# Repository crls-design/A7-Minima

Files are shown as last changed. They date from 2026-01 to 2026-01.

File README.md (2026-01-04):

# A7 Minima

A minimalist Artix-7 SoM in a credit-card form factor.

## Features

- XC7A100T-2 in CSG324 package
- 1GB DDR3 (32-bit, 800 Mbps)
- 32MB QSPI Flash
- On-board USB-to-JTAG + UART
- HDMI source connector
- 64 GPIOs compatible with perfboard
- 8 addressable RGB LEDs
- 2 single-color LEDs
- 3 slide switches
- 1 push button

## Documentation

See [`docs`](./docs/).

## Gallery




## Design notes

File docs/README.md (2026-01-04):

# Documentation

[Schematic](schematic.pdf)

## Pinouts & Template

See [`template`](../vivado/template/) folder for the `.ucf` and `.xdc` files, as well as top module instantiation template.

## Example Projects

- [LED Demo](../vivado/led_demo)
- [DDR3 Memory Test](../vivado/mem_test/)
- [Ben Eater's Breadboard Computer](https://github.com/CharlesSurianto/Ben-8-Bit/)

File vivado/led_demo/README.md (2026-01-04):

# LED Demo

This demo includes RGB binary counter and RGB Larson Scanner (fading variant), both of which are implemented purely in hardware.

## Gallery



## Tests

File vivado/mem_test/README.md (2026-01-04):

# Memory Test

This project implements a basic MicroBlaze system with DDR3 MIG interface running at 400MHz to verify the PCB's layout. Vitis memory tests example is used.

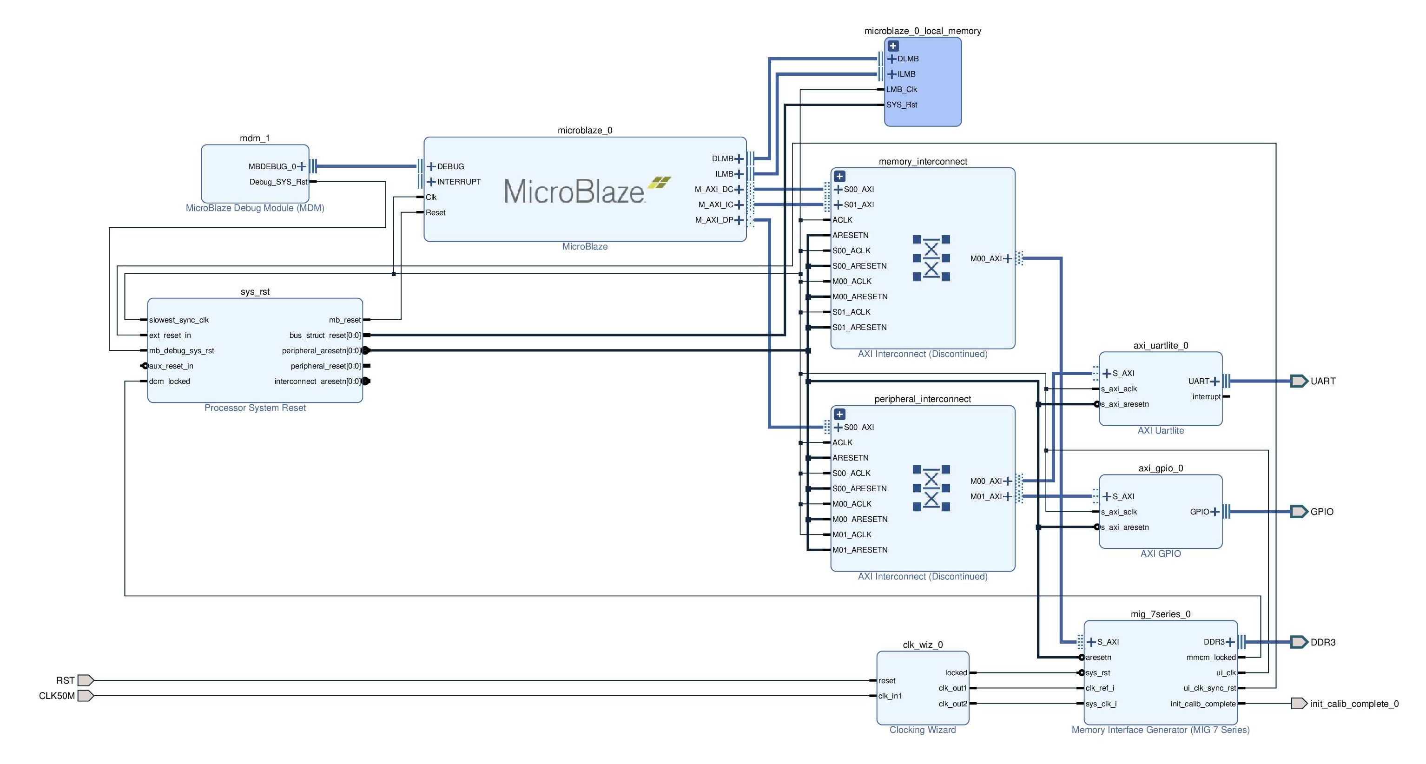
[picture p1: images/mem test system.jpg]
<br>

The MicroBlaze processor is clocked at 100MHz which is generated by the MIG. An external 50MHz oscillator from bank 14 is fed into a clocking wizard to generate 200MHz for `ref_clk` and 400MHz for `sys_clk`.

## Result

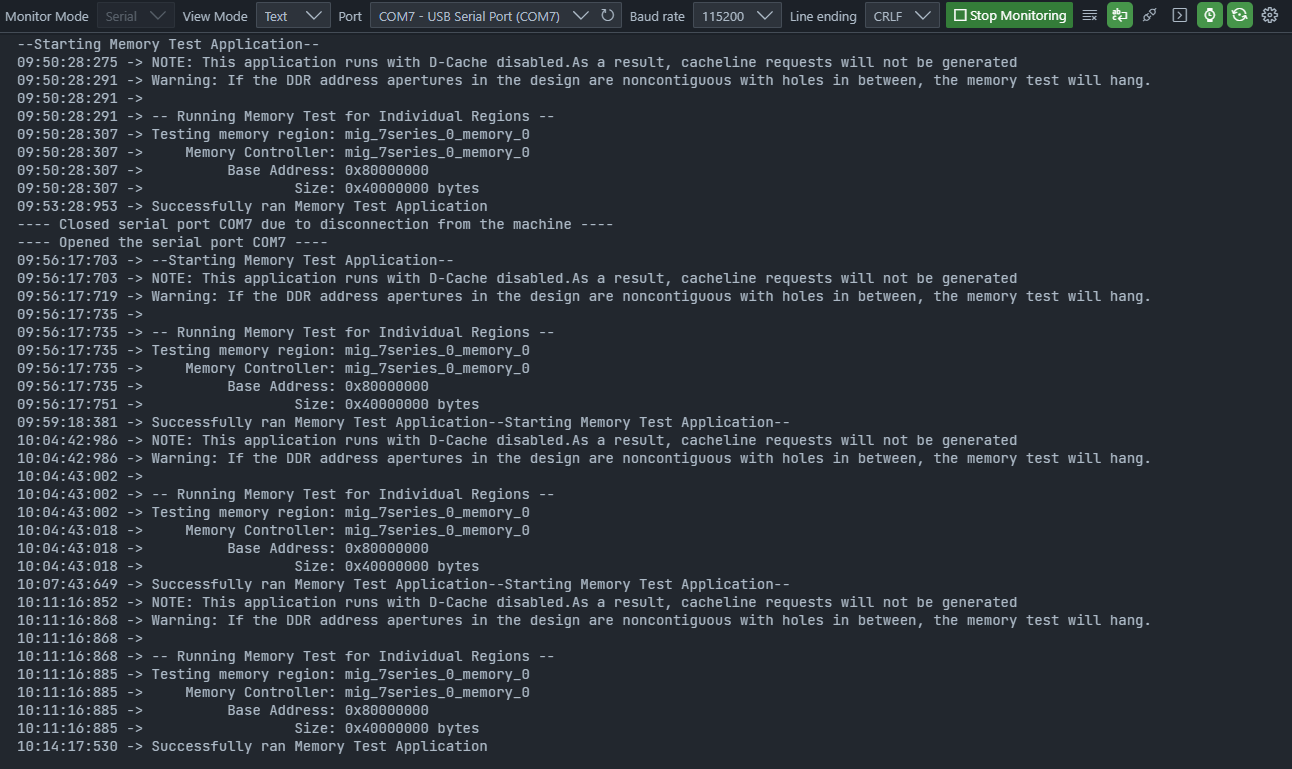
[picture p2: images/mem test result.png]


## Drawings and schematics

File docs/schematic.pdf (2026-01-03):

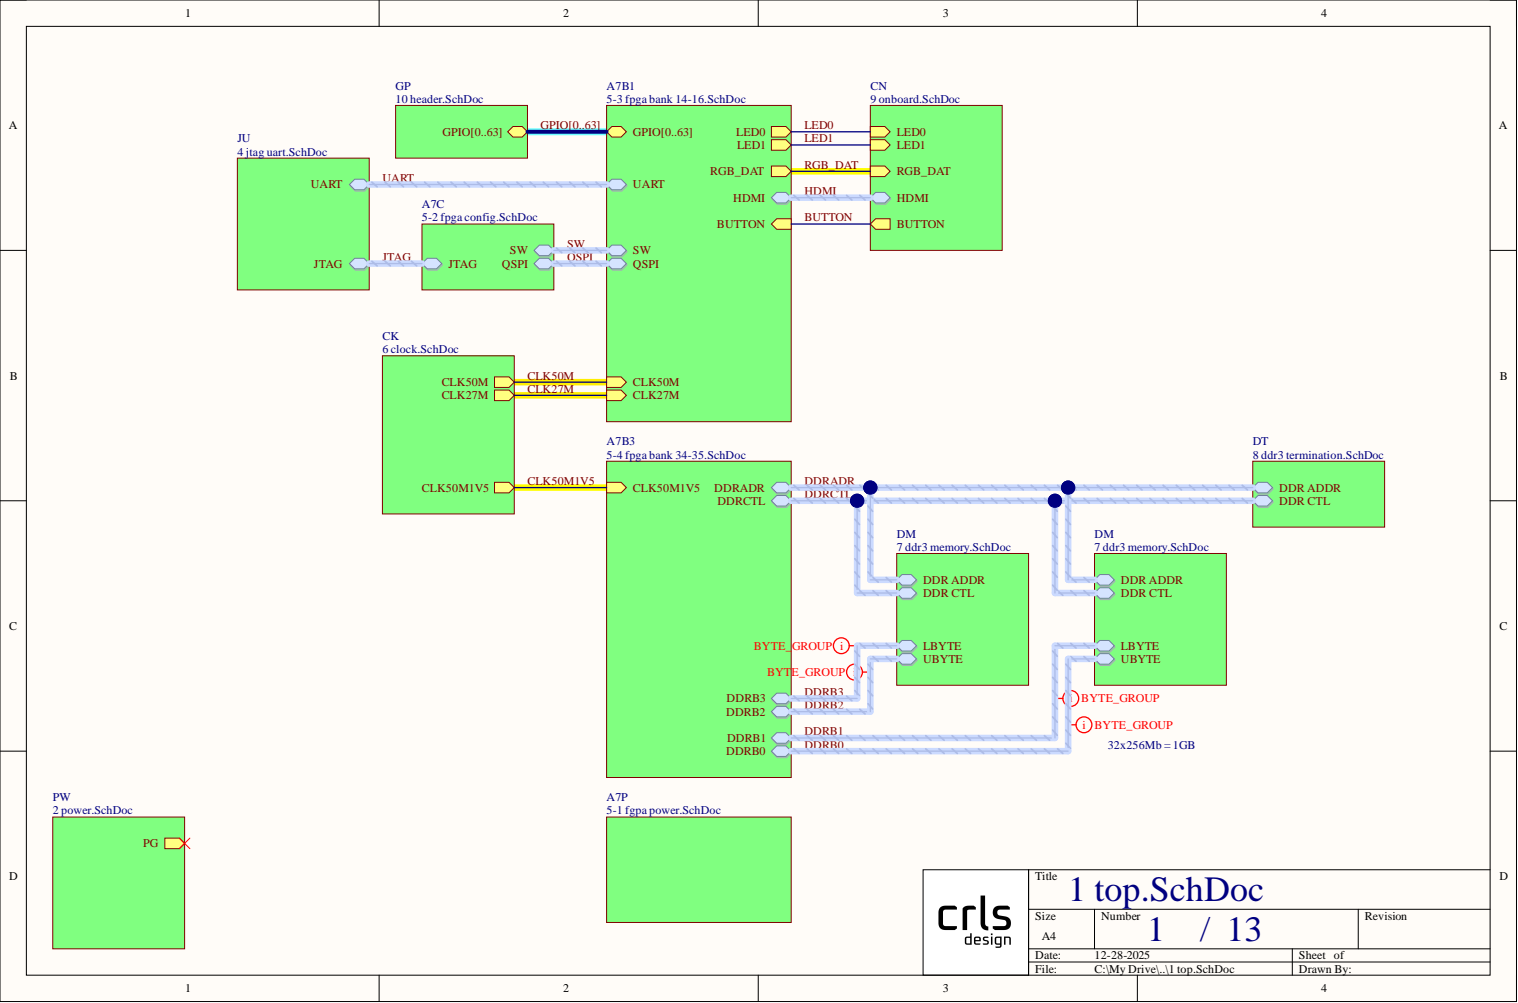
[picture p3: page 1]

DDRCTL

DM 7 ddr3 memory.SchDoc

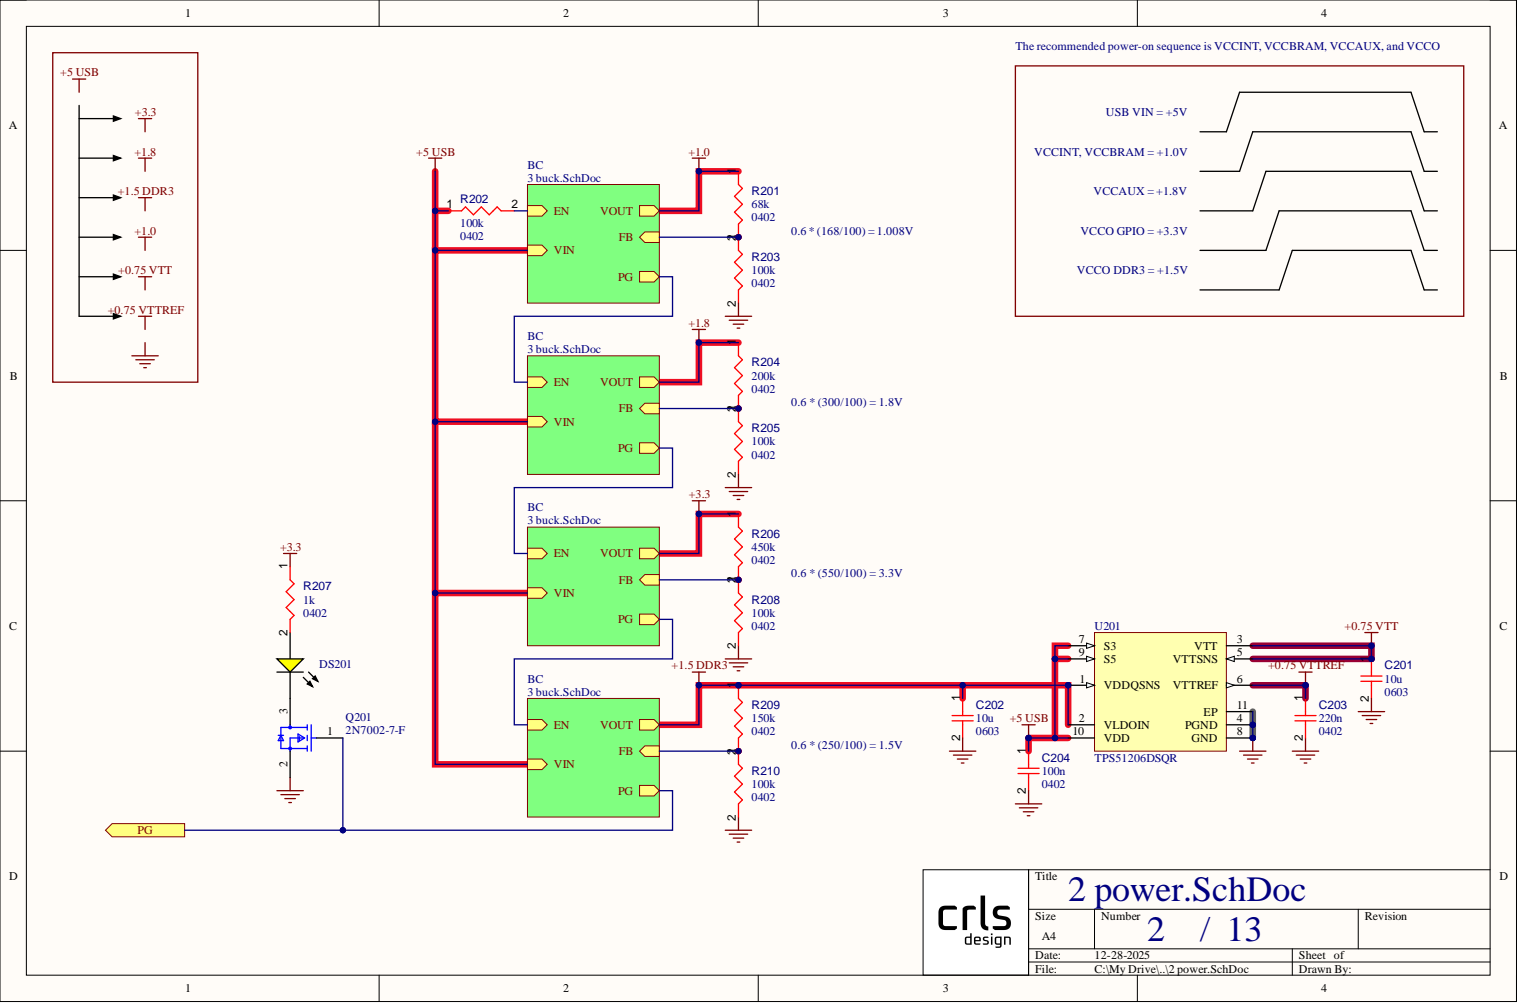
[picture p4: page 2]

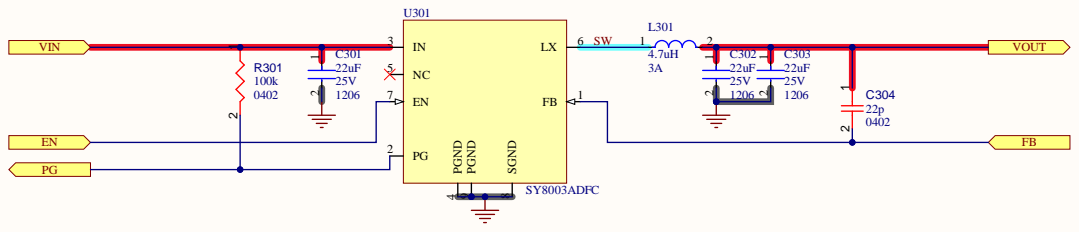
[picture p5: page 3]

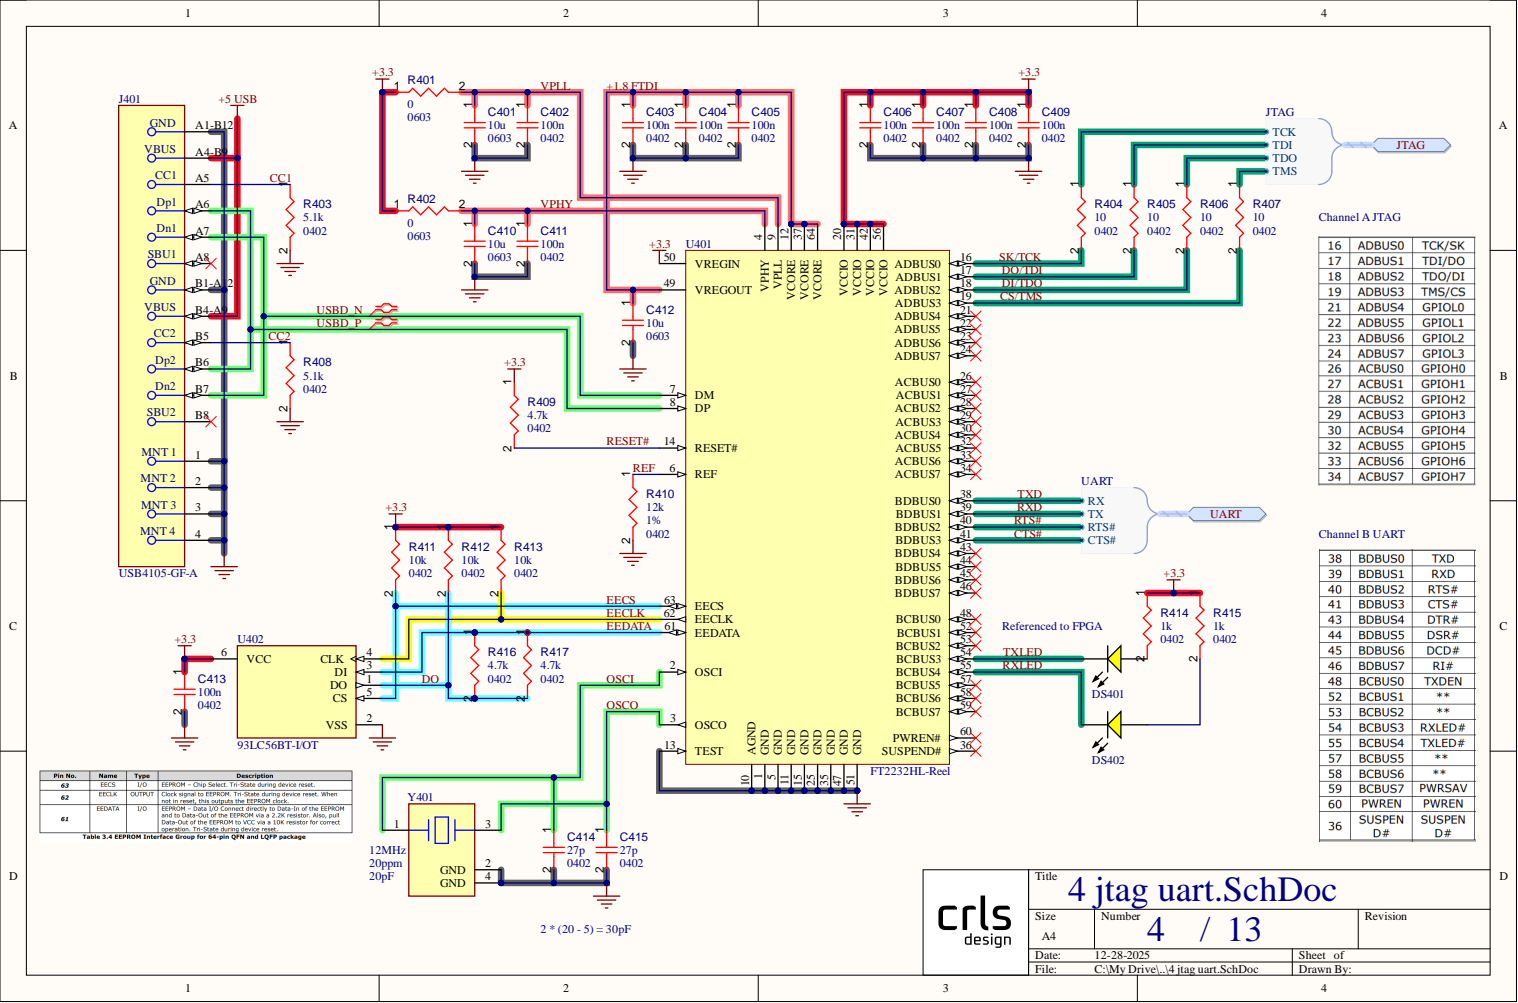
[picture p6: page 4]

EECLK | | EECLK 62
EEDATA | | | EEDATA 61

R416 | R417 | | OSCI 2

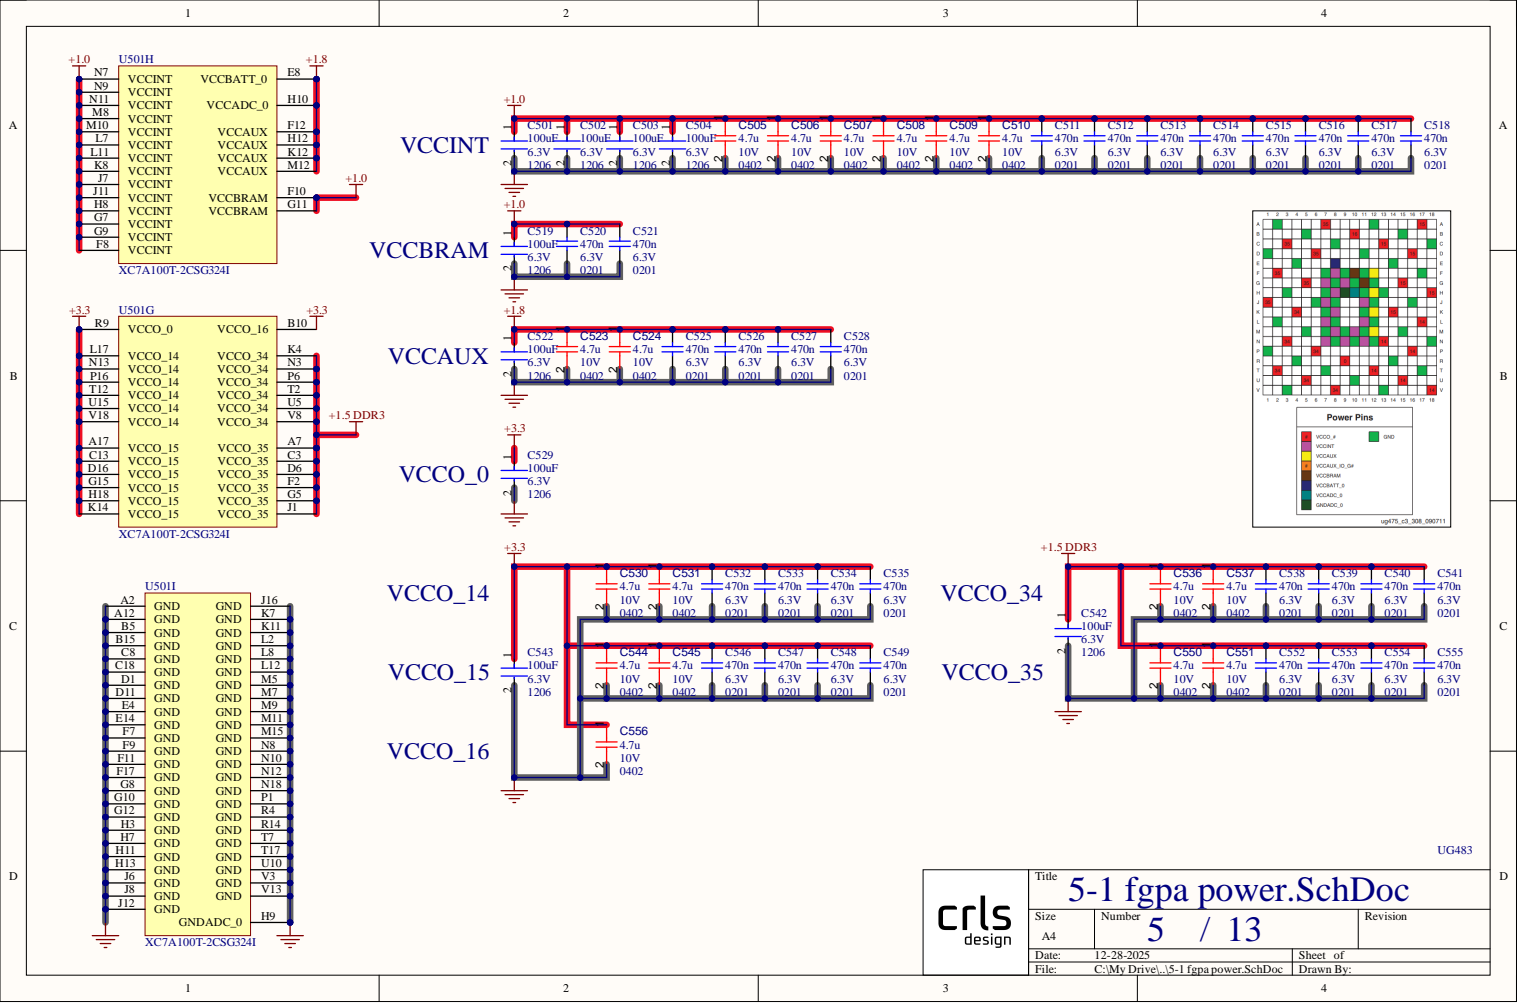
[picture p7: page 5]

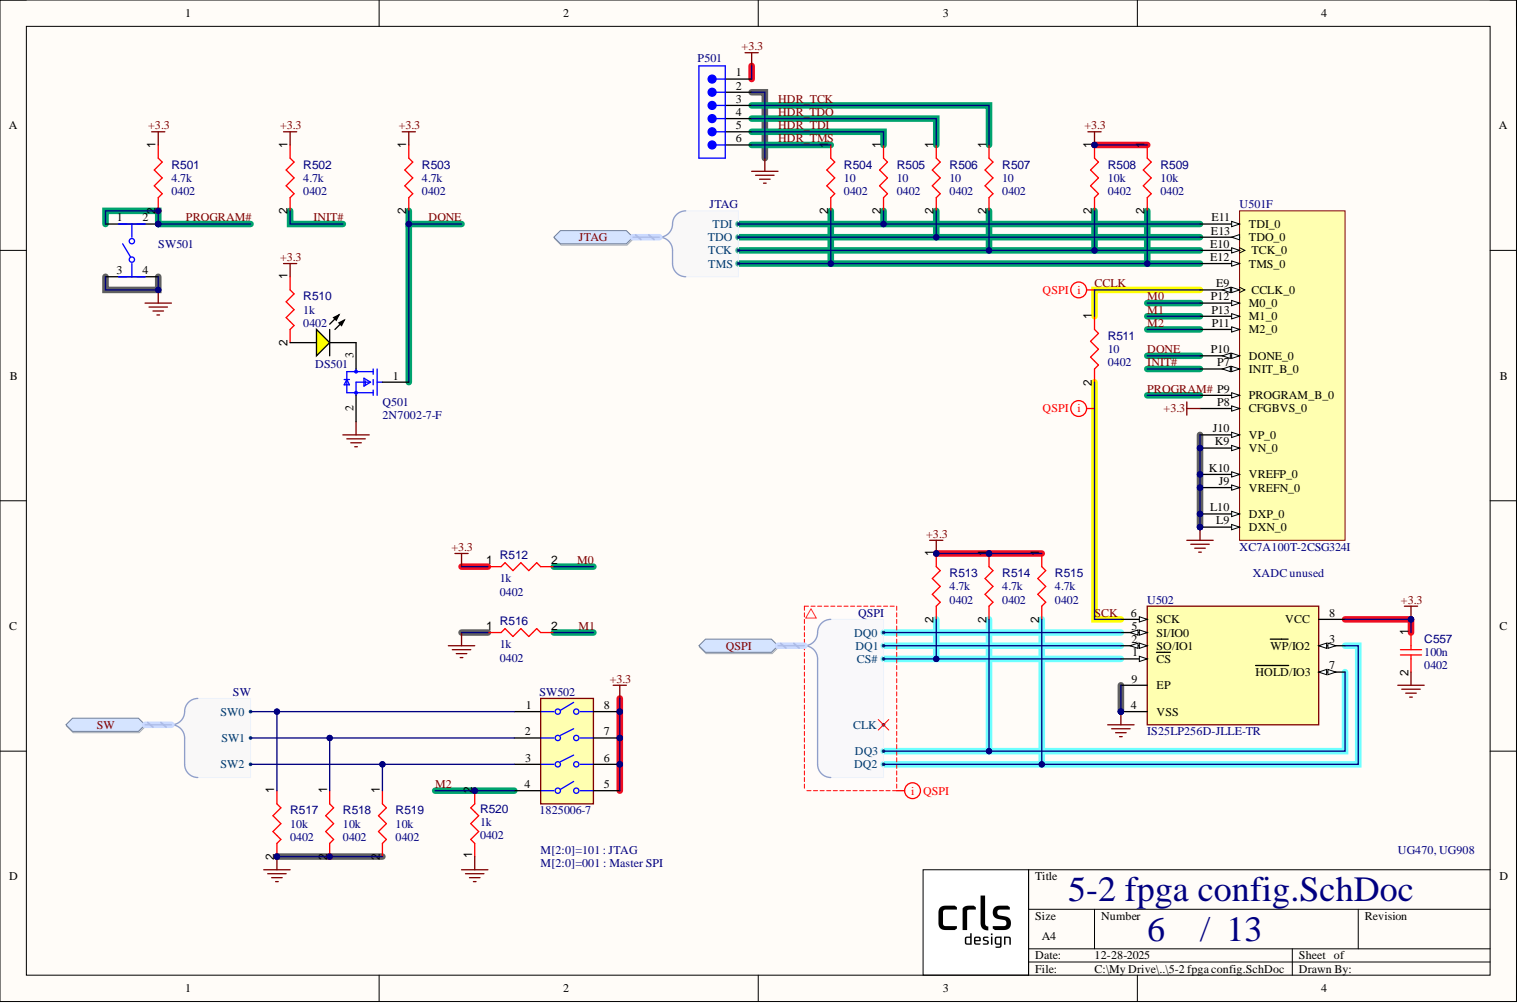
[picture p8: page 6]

CS 1 HOLD/IO3 | 7

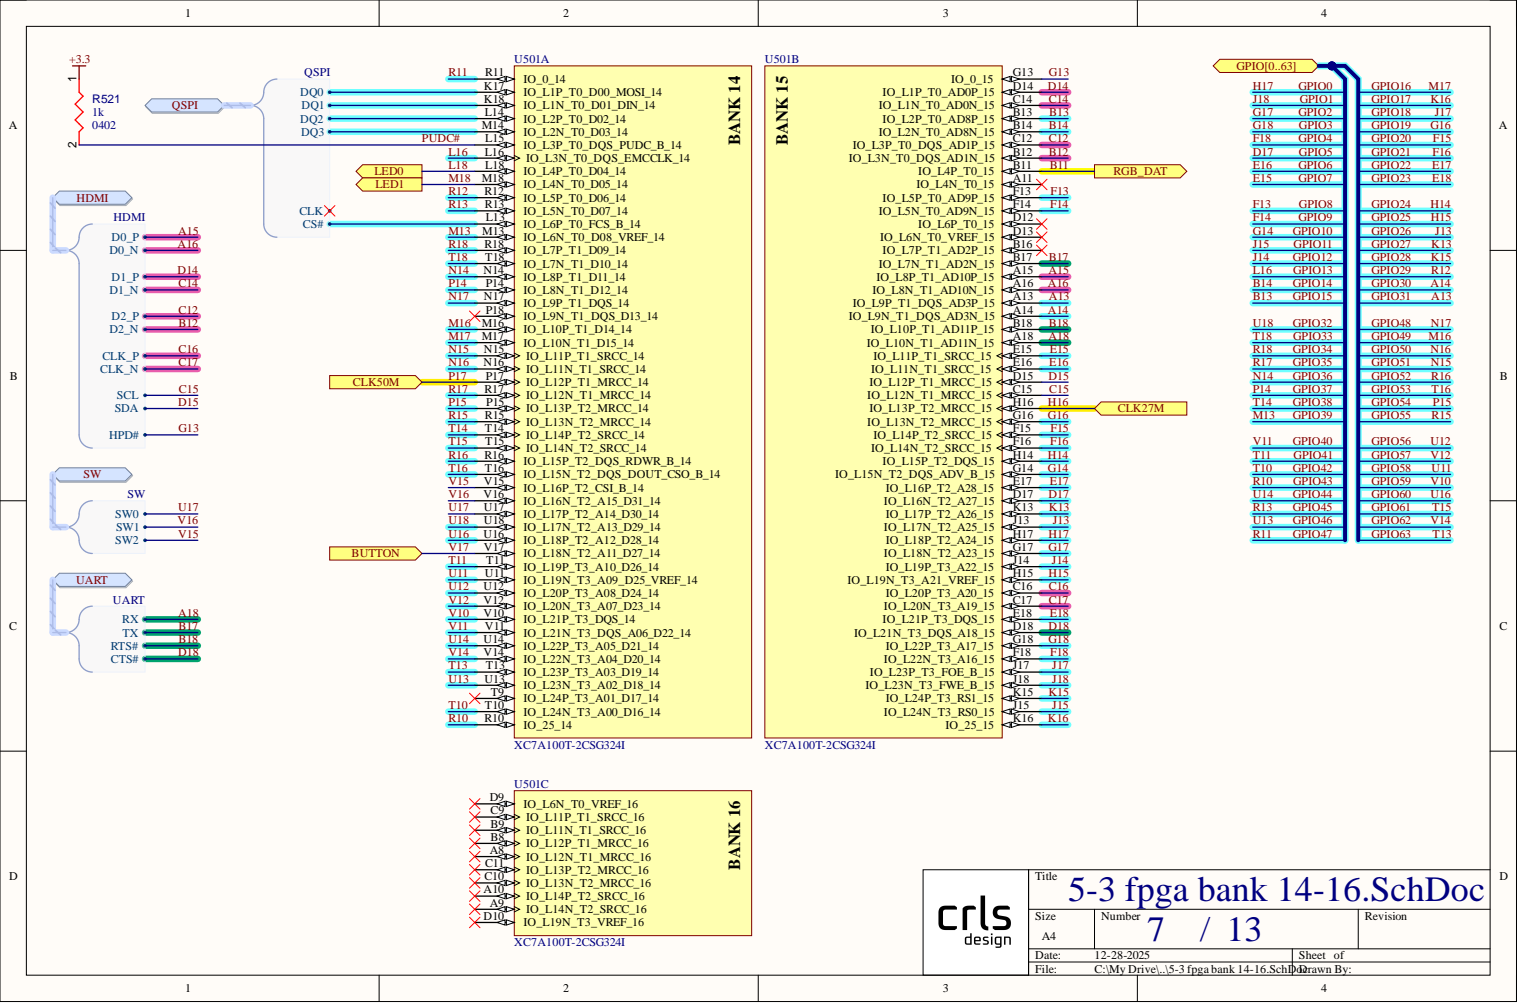
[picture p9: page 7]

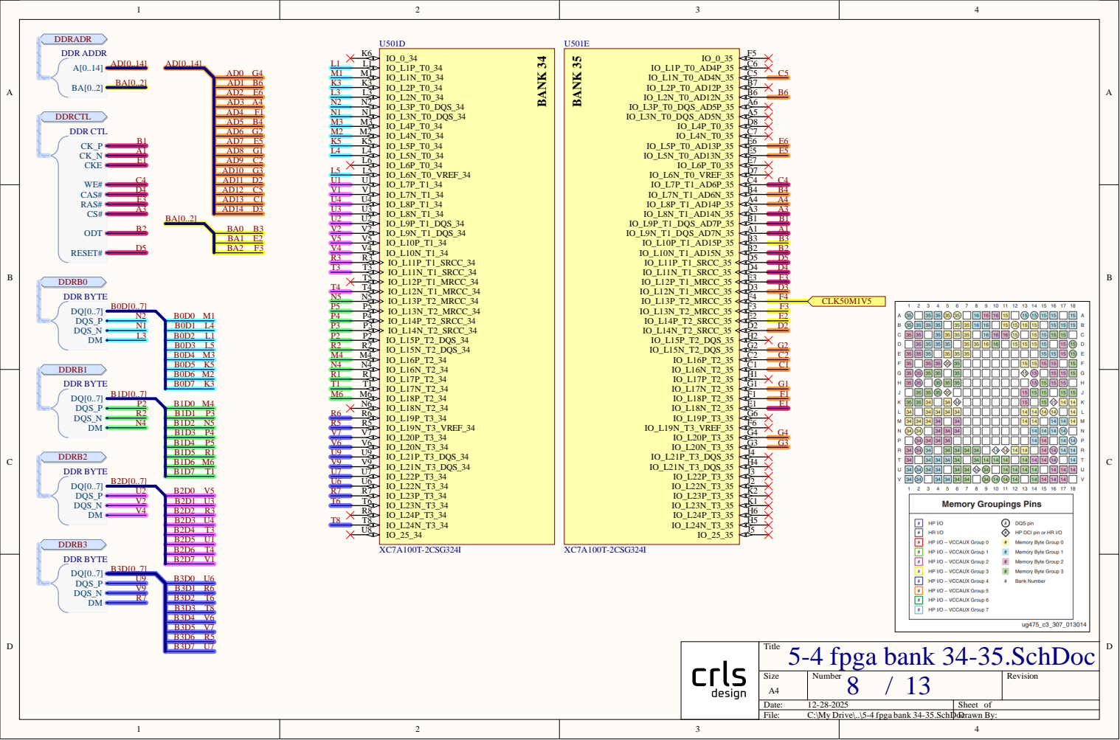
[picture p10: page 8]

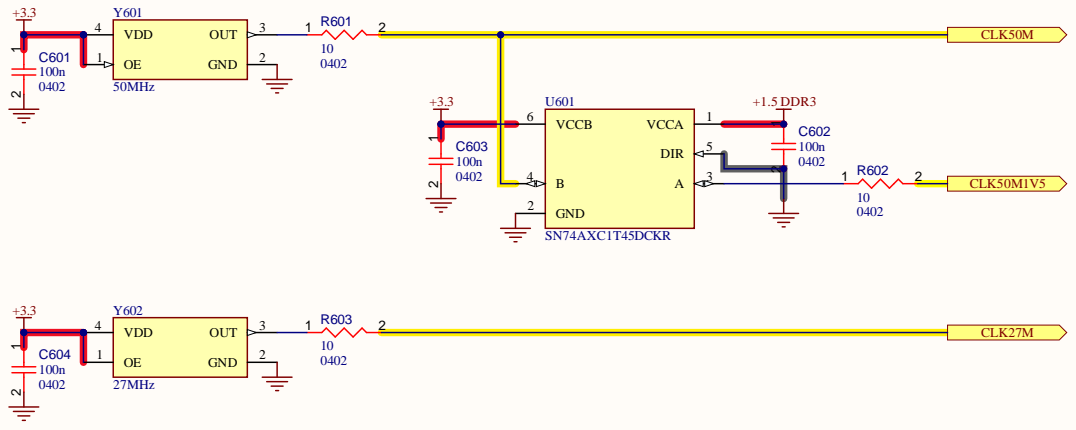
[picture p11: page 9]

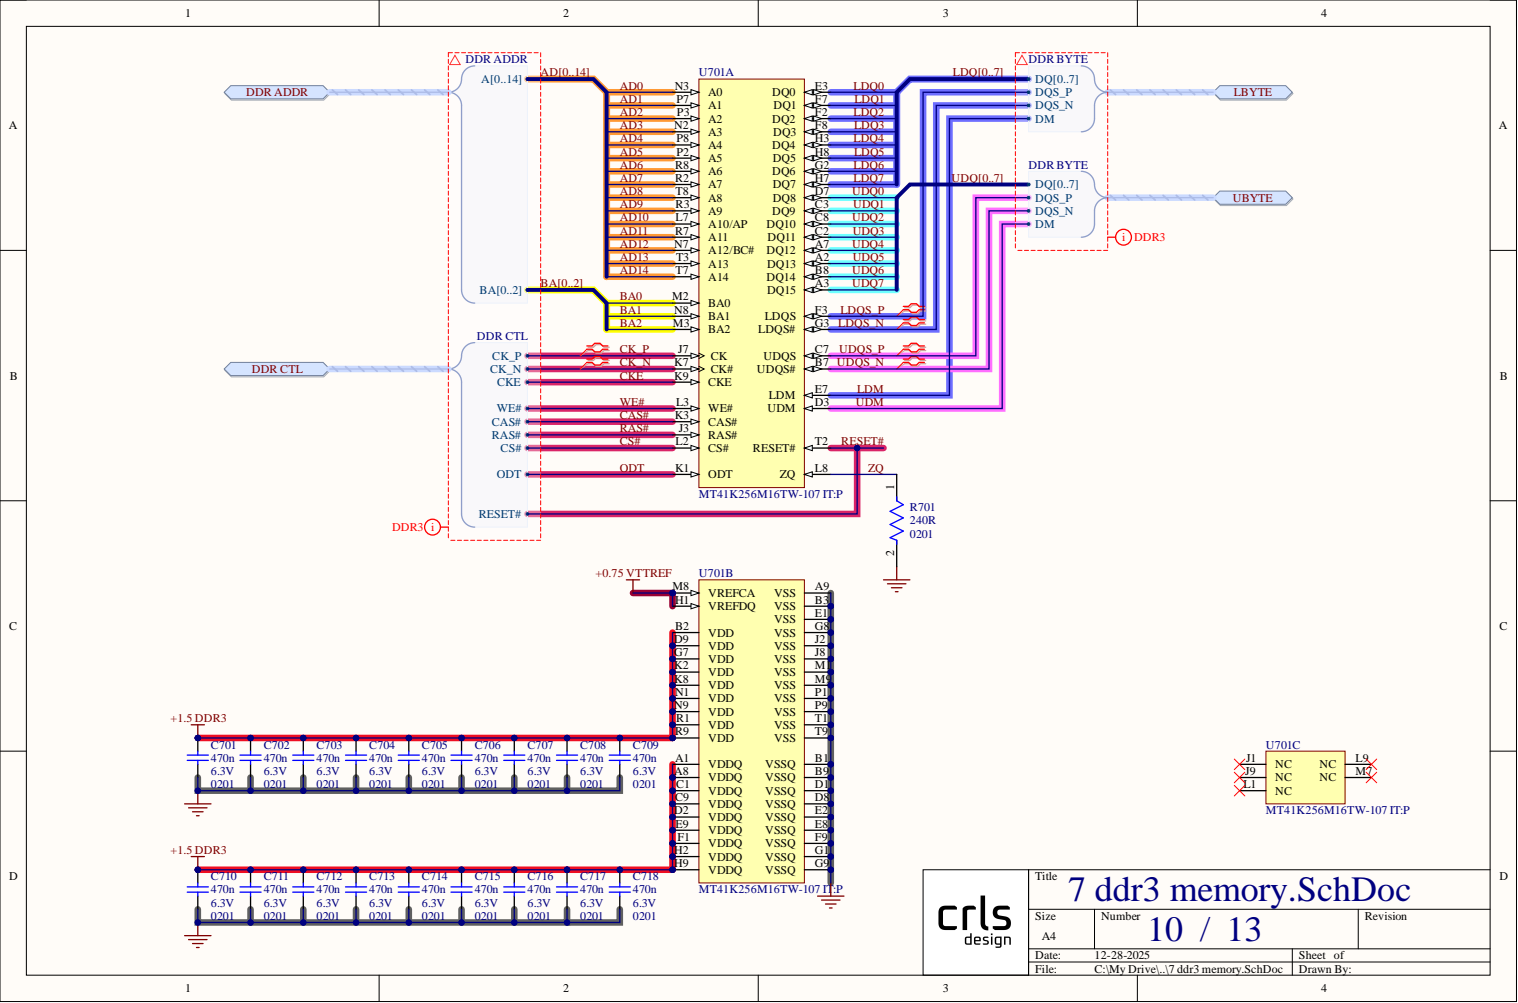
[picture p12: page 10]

L D Q 1
L D Q 2
L D Q 3 U D Q[0 . . 7 ]

U D Q 1
U D Q 2
U D Q 3

CK _N K 7 | | | U D Q S _N
CK E K 9 | | E 7 | L D M

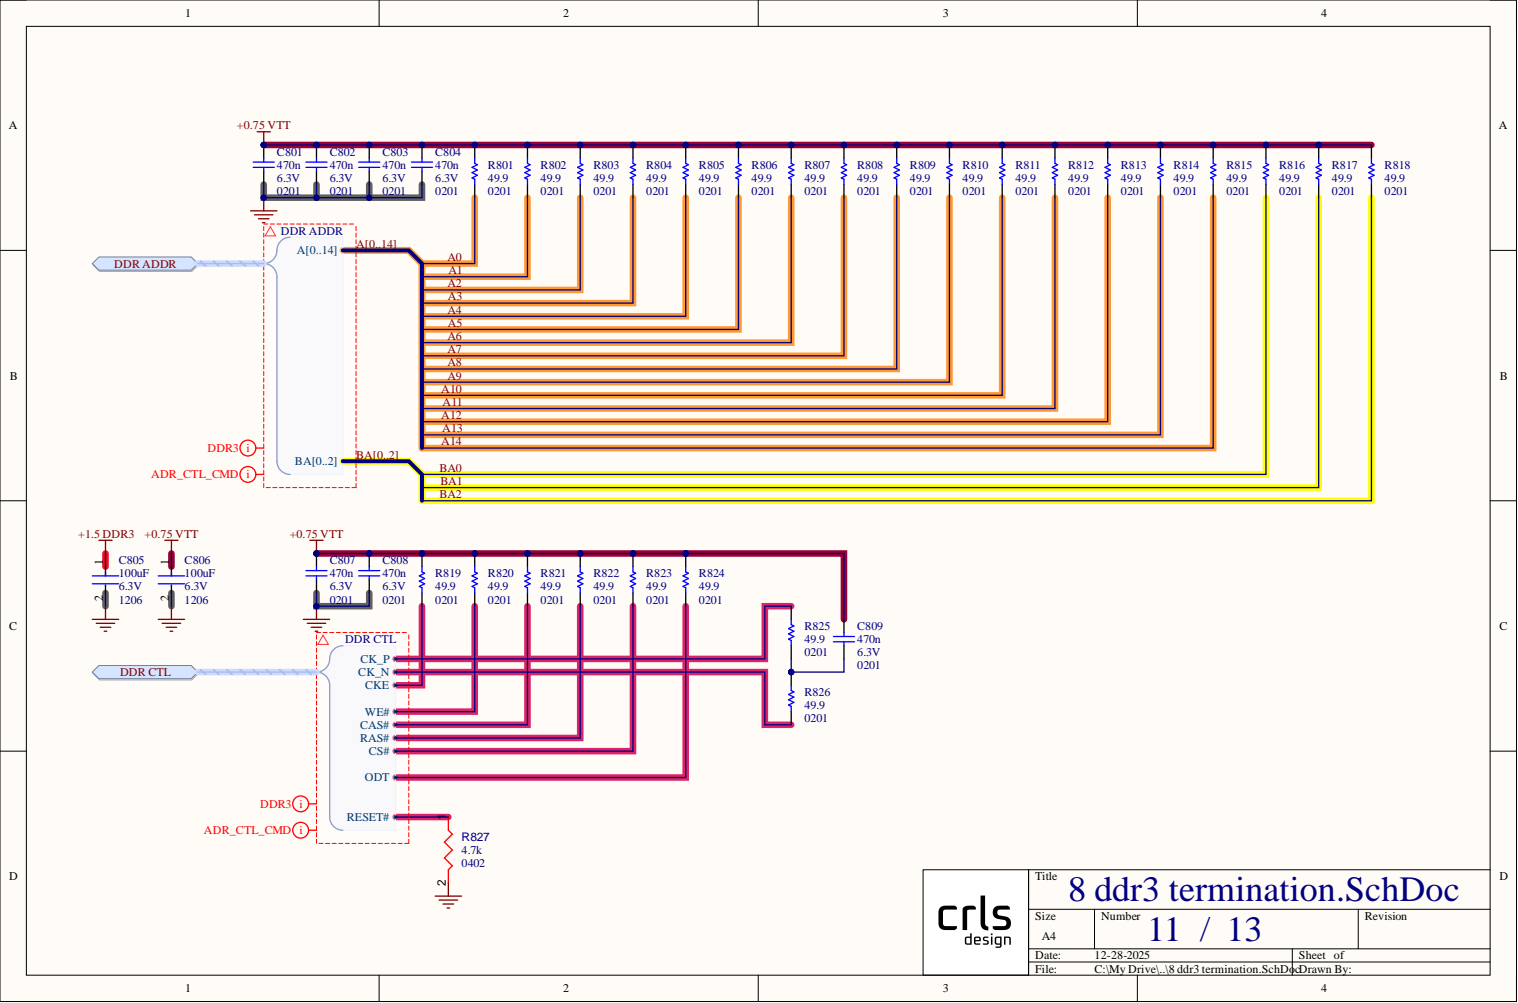
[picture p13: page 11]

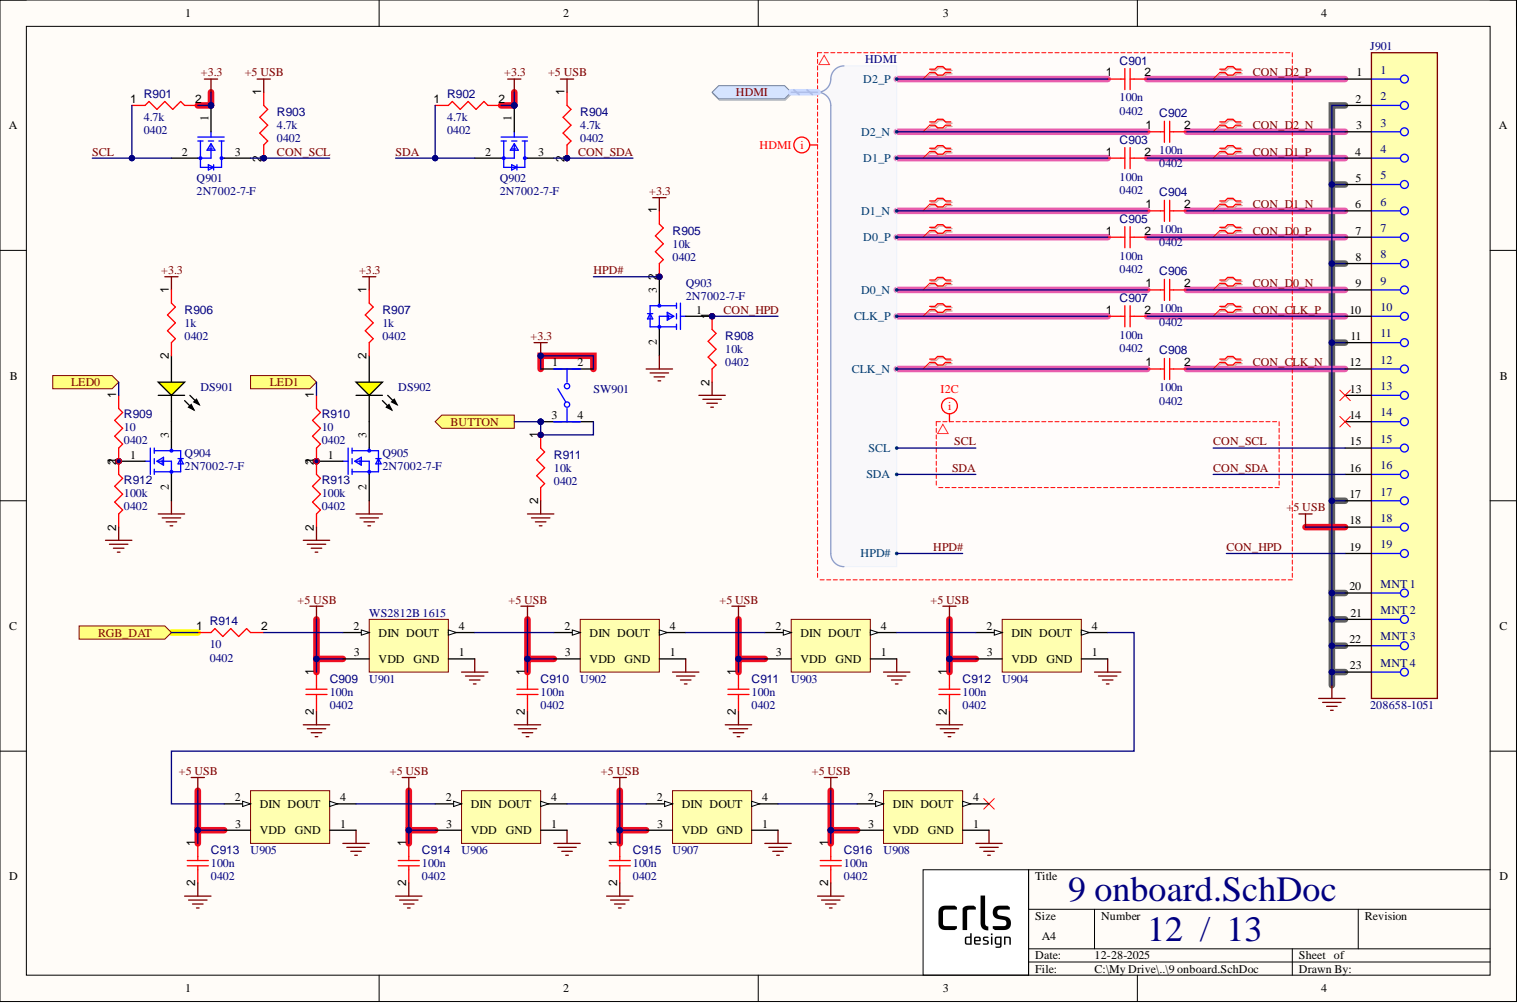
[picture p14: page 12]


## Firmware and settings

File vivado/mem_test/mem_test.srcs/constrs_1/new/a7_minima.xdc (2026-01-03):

## Clock Signals
# input CLK50M,
# input CLK27M,
# input CLK50M1V5,
set_property -dict { PACKAGE_PIN P17 IOSTANDARD LVCMOS33 } [get_ports { CLK50M }];
set_property -dict { PACKAGE_PIN H16 IOSTANDARD LVCMOS33 } [get_ports { CLK27M }];
set_property -dict { PACKAGE_PIN F4  IOSTANDARD LVCMOS15 } [get_ports { CLK50M1V5 }];
create_clock -add -name CLK50M    -period 20.00  -waveform {0 5} [get_ports { CLK50M }];
create_clock -add -name CLK27M    -period 37.037 -waveform {0 5} [get_ports { CLK27M }];
create_clock -add -name CLK50M1V5 -period 20.00  -waveform {0 5} [get_ports { CLK50M1V5 }];

## Switches
# input [2:0] SW,
set_property -dict { PACKAGE_PIN U17 IOSTANDARD LVCMOS33 } [get_ports { SW[0] }];
set_property -dict { PACKAGE_PIN V16 IOSTANDARD LVCMOS33 } [get_ports { SW[1] }];
set_property -dict { PACKAGE_PIN V15 IOSTANDARD LVCMOS33 } [get_ports { SW[2] }];

## Button
# input KEY,
set_property -dict { PACKAGE_PIN V17 IOSTANDARD LVCMOS33 } [get_ports { KEY }];

## LEDs
# output [1:0] LED,
set_property -dict { PACKAGE_PIN L18 IOSTANDARD LVCMOS33 } [get_ports { LED[0] }];
set_property -dict { PACKAGE_PIN M18 IOSTANDARD LVCMOS33 } [get_ports { LED[1] }];

## RGB LEDs
# output RGB_DAT,
set_property -dict { PACKAGE_PIN B11 IOSTANDARD LVCMOS33 } [get_ports { RGB_DAT }];

## GPIO
# inout [63:0] GPIO,
set_property -dict { PACKAGE_PIN H17 IOSTANDARD LVCMOS33 } [get_ports { GPIO[0] }];
set_property -dict { PACKAGE_PIN J18 IOSTANDARD LVCMOS33 } [get_ports { GPIO[1] }];
set_property -dict { PACKAGE_PIN G17 IOSTANDARD LVCMOS33 } [get_ports { GPIO[2] }];
set_property -dict { PACKAGE_PIN G18 IOSTANDARD LVCMOS33 } [get_ports { GPIO[3] }];
set_property -dict { PACKAGE_PIN F18 IOSTANDARD LVCMOS33 } [get_ports { GPIO[4] }];
set_property -dict { PACKAGE_PIN D17 IOSTANDARD LVCMOS33 } [get_ports { GPIO[5] }];
set_property -dict { PACKAGE_PIN E16 IOSTANDARD LVCMOS33 } [get_ports { GPIO[6] }];
set_property -dict { PACKAGE_PIN E15 IOSTANDARD LVCMOS33 } [get_ports { GPIO[7] }];

set_property -dict { PACKAGE_PIN F13 IOSTANDARD LVCMOS33 } [get_ports { GPIO[8] }];
set_property -dict { PACKAGE_PIN F14 IOSTANDARD LVCMOS33 } [get_ports { GPIO[9] }];
set_property -dict { PACKAGE_PIN G14 IOSTANDARD LVCMOS33 } [get_ports { GPIO[10] }];
set_property -dict { PACKAGE_PIN J15 IOSTANDARD LVCMOS33 } [get_ports { GPIO[11] }];
set_property -dict { PACKAGE_PIN J14 IOSTANDARD LVCMOS33 } [get_ports { GPIO[12] }];
set_property -dict { PACKAGE_PIN L16 IOSTANDARD LVCMOS33 } [get_ports { GPIO[13] }];
set_property -dict { PACKAGE_PIN B14 IOSTANDARD LVCMOS33 } [get_ports { GPIO[14] }];
set_property -dict { PACKAGE_PIN B13 IOSTANDARD LVCMOS33 } [get_ports { GPIO[15] }];

set_property -dict { PACKAGE_PIN M17 IOSTANDARD LVCMOS33 } [get_ports { GPIO[16] }];
set_property -dict { PACKAGE_PIN K16 IOSTANDARD LVCMOS33 } [get_ports { GPIO[17] }];
set_property -dict { PACKAGE_PIN J17 IOSTANDARD LVCMOS33 } [get_ports { GPIO[18] }];
set_property -dict { PACKAGE_PIN G16 IOSTANDARD LVCMOS33 } [get_ports { GPIO[19] }];
set_property -dict { PACKAGE_PIN F15 IOSTANDARD LVCMOS33 } [get_ports { GPIO[20] }];
set_property -dict { PACKAGE_PIN F16 IOSTANDARD LVCMOS33 } [get_ports { GPIO[21] }];
set_property -dict { PACKAGE_PIN E17 IOSTANDARD LVCMOS33 } [get_ports { GPIO[22] }];
set_property -dict { PACKAGE_PIN E18 IOSTANDARD LVCMOS33 } [get_ports { GPIO[23] }];

set_property -dict { PACKAGE_PIN H14 IOSTANDARD LVCMOS33 } [get_ports { GPIO[24] }];
set_property -dict { PACKAGE_PIN H15 IOSTANDARD LVCMOS33 } [get_ports { GPIO[25] }];
set_property -dict { PACKAGE_PIN J13 IOSTANDARD LVCMOS33 } [get_ports { GPIO[26] }];
set_property -dict { PACKAGE_PIN K13 IOSTANDARD LVCMOS33 } [get_ports { GPIO[27] }];
set_property -dict { PACKAGE_PIN K15 IOSTANDARD LVCMOS33 } [get_ports { GPIO[28] }];
set_property -dict { PACKAGE_PIN R12 IOSTANDARD LVCMOS33 } [get_ports { GPIO[29] }];
set_property -dict { PACKAGE_PIN A14 IOSTANDARD LVCMOS33 } [get_ports { GPIO[30] }];
set_property -dict { PACKAGE_PIN A13 IOSTANDARD LVCMOS33 } [get_ports { GPIO[31] }];

set_property -dict { PACKAGE_PIN U18 IOSTANDARD LVCMOS33 } [get_ports { GPIO[32] }];
set_property -dict { PACKAGE_PIN T18 IOSTANDARD LVCMOS33 } [get_ports { GPIO[33] }];
set_property -dict { PACKAGE_PIN R18 IOSTANDARD LVCMOS33 } [get_ports { GPIO[34] }];
set_property -dict { PACKAGE_PIN R17 IOSTANDARD LVCMOS33 } [get_ports { GPIO[35] }];
set_property -dict { PACKAGE_PIN N14 IOSTANDARD LVCMOS33 } [get_ports { GPIO[36] }];
set_property -dict { PACKAGE_PIN P14 IOSTANDARD LVCMOS33 } [get_ports { GPIO[37] }];
set_property -dict { PACKAGE_PIN T14 IOSTANDARD LVCMOS33 } [get_ports { GPIO[38] }];
set_property -dict { PACKAGE_PIN M13 IOSTANDARD LVCMOS33 } [get_ports { GPIO[39] }];
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

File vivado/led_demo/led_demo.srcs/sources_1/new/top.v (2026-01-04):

`timescale 1ns / 1ps

module top (
    input CLK50M,
    input CLK27M,
    input CLK50M1V5,

    input [2:0] SW,
    input KEY,
    output [1:0] LED,
    output RGB_DAT,

    inout [63:0] GPIO,

    input  UART_RX,
    output UART_TX,
    input  UART_RTS_N,
    output UART_CTS_N,

    // output [2:0] HDMI_D_P,
    // output [2:0] HDMI_D_N,
    // output HDMI_CK_P,
    // output HDMI_CK_N,
    output HDMI_SCL,
    inout  HDMI_SDA,
    input  HDMI_HPD_N,

    inout [31:0] DDR3_DQ,
    output [3:0] DDR3_DM,
    // inout [3:0] DDR3_DQS_P,
    // inout [3:0] DDR3_DQS_N,
    output [14:0] DDR3_ADDR,
    output [2:0] DDR3_BA,
    // output DDR3_CK_P,
    // output DDR3_CK_N,
    output DDR3_RAS_N,
    output DDR3_CAS_N,
    output DDR3_WE_N,
    output DDR3_RST_N,
    output DDR3_CKE,
    output DDR3_ODT,
    output DDR3_CS_N,

    inout [3:0] QSPI_DQ,
    output QSPI_CS_N
);
    integer i;
    genvar j;

    wire RST = KEY;

    // modes
    localparam SCANNER_TRAIL = 0, RGB_BINARY_COUNTER = 1;

    // constants
    reg [31:0] TICK_PERIODS[3:0];
    initial begin
        TICK_PERIODS[SCANNER_TRAIL] = 7142857 - 1;  // 7142857.14286 cycles @ 50MHz = 7Hz
        TICK_PERIODS[RGB_BINARY_COUNTER] = 488281 - 1;  // 488281.25 cycles @ 50MHz = 512/5 Hz
    end

    // sequential
    reg [1:0] mode;
    reg [31:0] tick_counter;  // overflowing counter
    reg [2:0] led_index;
    reg [15:0] counter;  // counts every tick
    reg rgb_updating;
    reg [23:0] scanner_fading[7:0];
    reg scanner_direction;

    // combinational
    reg [1:0] next_mode;
    wire tick_signal = tick_counter == 0;
    wire rgb_update_signal = rgb_updating && led_index == 7;
    reg [7:0] phases[2:0];
    reg zero_led_index;
    reg zero_counter;
    reg increment_led_index;
    reg next_rgb_updating;
    reg [23:0] rgb_data;
    reg rgb_we;
    reg [23:0] next_scanner_fading[7:0];

    // interconnects
    wire rgb_busy;
    wire [7:0] lut_data[2:0];

    ws2812 #(
        .INPUT_CLK_FREQ(50000000),
        .PWM_CLK_FREQ(800000),
        .US_RESET(300),
        .LED_COUNT(8)
    ) ws2812_inst (
        .CLK(CLK50M),
        .RST(RST),
        .WR_DATA(rgb_data),
        .WR_ADDR(led_index),
        .WR_EN(rgb_we),
        .START(rgb_update_signal),
        .BUSY(rgb_busy),
        .RGB_DAT(RGB_DAT)
    );

    generate
        for (j = 0; j < 3; j = j + 1) begin
            sin_lut sin_lut_inst (
                .PHASE(phases[j]),
                .VALUE(lut_data[j])
            );
        end
    endgenerate

    always @(posedge CLK50M or posedge RST) begin
        if (RST) begin
            mode <= SCANNER_TRAIL;
        end else if (tick_signal) begin
            mode <= next_mode;
        end
    end

    always @(posedge CLK50M or posedge RST) begin
        if (RST) begin
            tick_counter <= 0;
        end else begin
            if (tick_counter >= TICK_PERIODS[mode]) begin
                tick_counter <= 0;
            end else begin
                tick_counter <= tick_counter + 1;
            end
        end
    end

    always @(posedge CLK50M or posedge RST) begin
        if (RST) begin
            counter <= 0;
        end else begin
            if (tick_signal) begin
                if (zero_counter) begin
                    counter <= 0;
                end else begin
                    counter <= counter + 1;
                end
            end
        end
    end

    always @(posedge CLK50M or posedge RST) begin
        if (RST) begin
            led_index <= 0;
            rgb_updating <= 0;
        end else begin
            if (zero_led_index) begin
                led_index <= 0;
            end else if (increment_led_index) begin
                led_index <= led_index + 1;
            end
            rgb_updating <= next_rgb_updating;
        end
    end

    always @(posedge CLK50M or posedge RST) begin
        if (RST) begin
            scanner_direction <= 1;
            for (i = 0; i < 8; i = i + 1) begin
                scanner_fading[i] <= 0;
            end
        end else begin
            if (mode == SCANNER_TRAIL) begin
                if (tick_signal) begin
                    if (counter[2:0] == 3'd7) scanner_direction <= ~scanner_direction;
                    for (i = 0; i < 8; i = i + 1) begin
                        scanner_fading[i] <= next_scanner_fading[i];
                    end
                end
            end else begin
                scanner_direction <= 1;
                for (i = 0; i < 8; i = i + 1) begin
                    scanner_fading[i] <= 0;
                end
            end
        end
    end

    always @(*) begin
        next_rgb_updating = rgb_updating;
        increment_led_index = 0;
        zero_led_index = 0;
        rgb_we = 0;

        if (rgb_updating) begin
            increment_led_index = 1;
            rgb_we = 1;
            if (led_index >= 7) begin
                next_rgb_updating = 0;
                zero_led_index = 1;
            end
        end else begin
            if (tick_signal) begin
                next_rgb_updating = 1;
                zero_led_index = 1;
            end
        end
    end

    always @(*) begin
        next_mode = mode;
        zero_counter = 0;
        rgb_data = 24'd0;
        phases[0] = 0;
        phases[1] = 0;
        phases[2] = 0;
        for (i = 0; i < 8; i = i + 1) begin
            next_scanner_fading[i] = 0;
        end

        case (mode)
            SCANNER_TRAIL: begin
                phases[0] = {counter[4:0], 3'd0};
                phases[1] = {counter[4:0], 3'd0} + 7'd85;
                phases[2] = {counter[4:0], 3'd0} - 7'd85;
                rgb_data  = scanner_fading[led_index];
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

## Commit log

2026-01-03 add schematic print
2026-01-04 add altium source
    [1 top.SchDoc, 10 header.SchDoc, 2 power.SchDoc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]
2026-01-04 add led demo source
